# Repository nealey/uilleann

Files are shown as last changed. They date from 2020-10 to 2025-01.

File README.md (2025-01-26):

Uilleann
=======

This is my work to model a 3D printable Uilleann Pipe full set.

I need a better name for this project.

Printing Advice
=============

Reeds
------

The Daye drones feature 3D printable reeds,
based on the laudable work of Animatorgeek.
Reeds need to simulate natural cane,
so the following print settings should be used on every reed:

Fill pattern: Aligned Rectilinear  
Fill density: 100%  
Fill angle: 90°  
Bottom solid layers: 0  
Layer height: 0.05  
Perimiters: 1  
Seam position:  Aligned (or whatever gets seams off the reed and onto the base)  
Top solid layers: 0  

Some light sanding may be required after printing.

Daye
====

Based on David Daye's Budget Drones and Penny Chanter owned by me.
David Daye has published extensive notes on how to recreate his builds
at <https://daye1.com/>, including measurements for these parts.

Rowsome
=======

This is based on the O'Flynn Leo Rewsome set,
documented at pipers.id.

http://pipers.ie/source/section/?sectionId=8 has been invaluable, providing
detailed documentation of measurements of pipes.

* [photos](https://pipers.ie/source/gallery?galleryId=115)
* [diagrams](http://pipers.ie/source/gallery?galleryId=1353)

Decorations
----------

The diagrams didn't specify exact values for every measurement,
so I took some aesthetic liberties with some parts (mostly decorative ones).

Bump-Outs
----------

I think this chanter has some extra keys that I'm not going to implement,
so I skipped a lot of the bump-out warty things on the side.

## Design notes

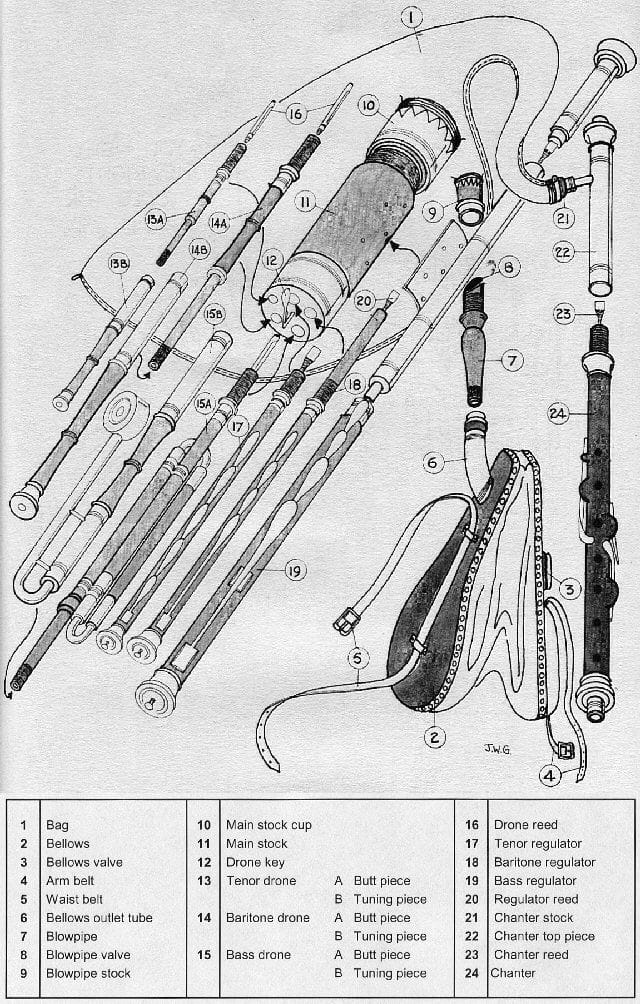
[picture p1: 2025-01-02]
doc/full-set-names.jpg

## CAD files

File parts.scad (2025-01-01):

// Make circles circular in final renders.
$fn = $preview ? 0 : 60;

module brass() {
  color("gold") children();
}

module derlin() {
  color("steelblue") children();
}

// tube creates a hollow cylinder
module tube(h=10, id=5, od=10) {
  difference() {
    cylinder(h=h, d=od);
    cylinder(h=h, d=id);
  }
}

// default height of rings
rings_height = 1.8;

// rings of adornment.
// This engraves two rings, 1.4mm apart, at a depth of 0.4.
module rings(h=0.4, d=1, depth=0.4, spacing=1.4) {
  tube(h=h, id=d-depth, od=d);
  translate([0, 0, spacing]) tube(h=h, id=d-depth, od=d);
}

// default brass tube thickness
brass_thickness = 0.75;

// brass_tube creates a chamfered hollow cylinder with given inside diameter,
// and wall thickness of 0.75.
// Decorative rings are etched into the top and bottom.
module brass_tube(h=10, d=10, t=brass_thickness) {
  id = d;
  od = id + (t*2);
  cd = (id + od) / 2; // Chamfer diameter

  brass() {
    difference() {
      tube(h=h, id=id, od=od);

      // Chamfered ends
      translate([0, 0, 0]) cylinder(h=1, d1=cd, d2=id);
      translate([0, 0, h-1]) cylinder(h=1, d1=id, d2=cd);

      translate([0, 0, 2]) rings(d=od);
      translate([0, 0, h-2-rings_height]) rings(d=od);
    }
  }
}

// derlin_tube is a non-chamfered sky blue tube.
// I use blue so it's easier to see in preview.
module derlin_tube(h=10, id=5, od=10) {
  derlin() {
    tube(h=h, id=id, od=od);
  }
}

// derlin_stop is a derlin tube, chamfered on one end.
module derlin_stop(h=10, id=5, od=10) {
  chamferh = h/5;
  derlin() {
    difference() {
      union() {
        cylinder(h=h-chamferh, d=od);
        translate([0, 0, h-chamferh]) cylinder(h=chamferh, d1=od, d2=id);
        }
      cylinder(h=h, d=id);
      }
    }
}

// default bell height
bell_height = 17;

// derlin_bell makes a decorative flared bell.
// od will default to 33% larger than id.
module derlin_bell(h=bell_height, id=5, od=0) {
  chamferh = 1;
  chamferd = 1;
  ringsmargin = 1;
  toph = rings_height + ringsmargin*2 + chamferh;
  flareh = h - toph;
  od = (od == 0) ? (id * 1.33) : od;
  derlin() {
    difference() {
      union() {
        cylinder(h=flareh, d1=id, d2=od);
        translate([0, 0, flareh]) cylinder(h=toph-chamferh, d=od);
        translate([0, 0, flareh+toph-chamferh]) cylinder(h=chamferh, d1=od, d2=od-chamferd);
      }
      cylinder(h=h, d=id);
      translate([0, 0, flareh + ringsmargin]) rings(d=od);
    }
  }
}

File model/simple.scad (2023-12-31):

// Based on O'Flynn Rowsome Chanter Measurements
// http://pipers.ie/source/media/?mediaId=31307&galleryId=1353

// DIameter of screw hole
Screwhole = 4; // [1:10]

// Part to generate
Part = "all"; // [all, top-front, top-back, bottom-front, bottom-back]


module metal() {
    color("silver") children();
}

module leather() {
    color("sienna") children();
}

module ivory() {
    color("wheat") children();
}

module wood() {
    color("saddlebrown") children();
}

// A shape like a hamburger patty
module patty(h, d) {
    intersection() {
        cylinder(h=h, d=d);
        translate([0, 0, h/2]) {
            resize([d, d, h*3]) {
                sphere(d=d);
            }
        }
    }
}    

// A cylinder with something like a compression fitting around it
module ringyding(h, id, od) {
    margin = h * 0.1;
    union() {
        leather() cylinder(h=h, d=id);
        translate([0, 0, margin]) ivory() patty(h=h*0.8, d=od);
    }
}

// A fillet is a sort of trumpet bell shape
module fillet(h, d1, d2) {
    r = abs(d1-d2)/2;
    resize([d1, d1, h]) {
        rotate_extrude() {
            translate([d2/2, 0, 0]) {
                difference() {
                    square([r, r]);
                    translate([r, r]) circle(r=r);
                }
            }
        }
    }
}

// An upside-down fillet
module tellif(h, d2, d1) {
    translate([0, 0, h]) mirror([0, 0, 1]) fillet(h, d1, d2);
}

// Absolutely nothing: helps make the code look better
module nothing(h) {
}

// Just a rotated cylinder
// h: height of the *top* of the protrusion
// d: height of the protrusion (diameter?)
// protrusion: amount of protrusion
module bumpout(h, d, protrusion) {
    intersection() {
        translate([0, -protrusion, h-d]) {
            cylinder(h=d, d=20.4);
        }
        translate([0, -protrusion, h-d/2]) {
            sphere(d=protrusion*4);
        }
        translate([0, 0, h-d]) {
            cylinder(h=d, d1=19, d2=50);
        }
    }
}


// A tonehole with :
// * height=h
module tonehole(h) {
    translate([0, 5, h]) {
        rotate(a=90, v=[1, 0, 0]) {
            resize([Screwhole, Screwhole, 100]) {
                cylinder(h=100, d=100);
            }
        }
    }
}

module chanter() {
    difference() {
        union() {
            translate([0, 0,  0]) metal() cylinder(h=22.0, d=17.1);
            translate([0, 0, 22]) wood() cylinder(h=23.5, d=17.1);  // Rings go around this
            
            // Decorative stuff on the bottom
            translate([0, 0, 32]) {          
                translate([0, 0, 0.0]) ivory() patty(h=3.4, d=28.7);
                translate([0, 0, 3.4]) leather() fillet(h=1.8, d1=27, d2=22);
                translate([0, 0, 4.1]) ringyding(h=4.1, id=21, od=24);
                translate([0, 0, 8.2]) ringyding(h=5.3, id=21, od=24);
            }

            // A taper on that bottom ring so it will print nicely
            translate([0, 0, 12]) wood() tellif(h=20, d1=25.5, d2=100);
            
            // Main body
            translate([0, 0, 45.5]) wood() cylinder(h=244.9, d1=20.4, d2=18);
            
            // Top decoration
            translate([0, 0, 290.4]) {
                color("silver") cylinder(h=40.8, d=17);
                
                translate([0, 0,  0.0]) ringyding(h=5.5, id=19, od=21);
                translate([0, 0,  5.5]) nothing(h=9.7); // metal
                translate([0, 0, 15.2]) ringyding(h=4.3, id=18, od=20.7);
                translate([0, 0, 19.5]) nothing(h=6.7); // metal
                translate([0, 0, 26.2]) ivory() patty(h=2, d=20.2);
                translate([0, 0, 28.2]) leather() tellif(h=8, d2=19, d1=23);
                translate([0, 0, 36.2]) ivory() patty(h=4.6, d=25.4);
            }
            
            // I presume this protects the reed and provides a place for tubing to connect
            translate([0, 0, 324.5]) metal() cylinder(h=32.7, d=14.8);
            
            // Bumpouts
            // These angles are my best guess based on photos
            rotate(220) wood() bumpout(161.2, 14.8, 6); // protrusion guessed
        }

        // Tone Holes!
        translate([0, 0, 5]) { // This offset is specified nowhere. I'm guessing to make it fit the bumpouts.
            rotate(180) tonehole(263.0); // back D
            rotate(0) tonehole(246.4); // C♯
            rotate(0) tonehole(216.2); // B
            rotate(0) tonehole(182.0); // A
            rotate(0) tonehole(147.4); //  G
            rotate(0) tonehole(116.2); // F♯
            rotate(0) tonehole(84.7); // E
            rotate(-10) tonehole(53.3); // E♭
        }
    }
}

intersection() {
    chanter();
    cube(400);
}

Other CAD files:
daye/common.scad
rowsome/chanter-full.scad
daye/chanter/chanter-bottom.scad
daye/chanter/chanter-top.scad
daye/chanter/chanter.scad
daye/chanter/reed.scad
daye/drones/assembly.scad
daye/drones/baritone/assembly.scad
daye/drones/baritone/reed-body.scad
daye/drones/baritone/reed.scad
daye/drones/baritone/tuner-barrel.scad
daye/drones/baritone/tuner-end.scad
daye/drones/bass/assembly.scad
daye/drones/tenor/assembly.scad
daye/drones/tenor/tuner-barrel.scad
daye/drones/tenor/tuner-end.scad
rowsome/chanter.scad

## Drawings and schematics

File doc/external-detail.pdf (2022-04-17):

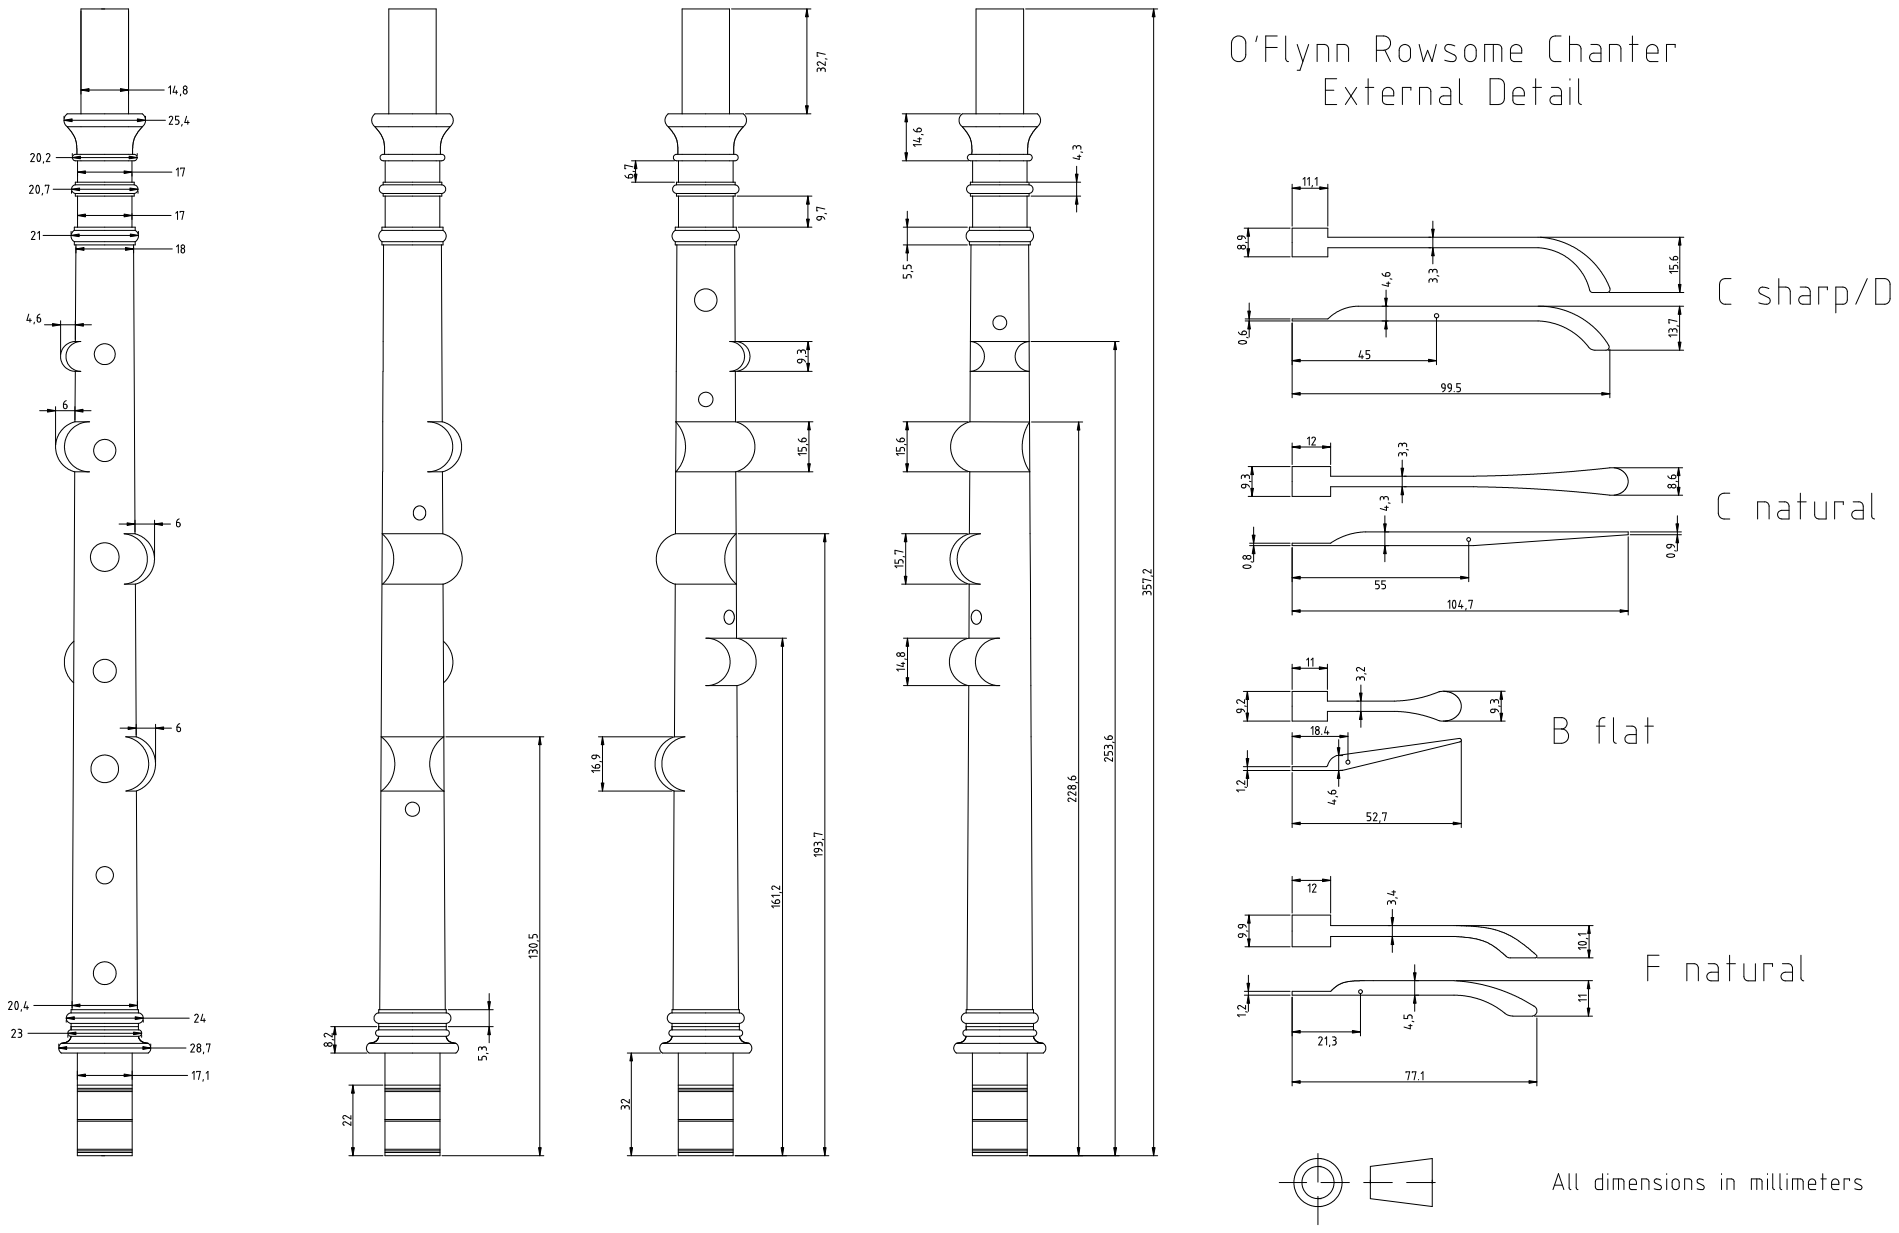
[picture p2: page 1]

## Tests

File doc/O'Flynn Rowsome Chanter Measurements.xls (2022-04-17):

All measurements in millimetres
OAL: 357.2 [±0.05] |  |  |  |  |  | Bore comments
Minimum bore diameter: 5.57 [±0.005] |  |  |  |  |  | Bore contained two rushes, each having a diameter of 0.9 and a length of 272
Round |  |  | Oval |  |  |  |  | Tone holes
Probe # | Actual diameter [±0.005] | Insertion distance [±0.5] | Probe # | Actual diameter [±0.005] | Insertion distance [±0.5] |  |  | Tonehole | Transverse diameter [±0.005] | Longitudinal diameter [±0.005] | Chimney height [±0.05] | Distance from bell to lower tonehole edge [±0.05] | Comments
71 | 7.1 | 357 | - | - | - | Approximate reed dimensions |  | back D | 6.04 | 7.95 | 10.1 | 263
70 | 7 | 344 | - | - | - | Overall length | 86.5 | high C sharp/D | 4.39 | 4.36 | 11.1 | 257.3
69 | 6.91 | 344 | - | - | - | Head width | 12.8 | C sharp | 6.42 | 6.57 | 11.3 | 246.4
68 | 6.8 | 344 | - | - | - | Scrape length | 22.5 | C natural | 4.5 | 4.5 | 11.5 | 233.3
67 | 6.7 | 344 | - | - | - | Staple length | 55.5 | B | 6.89 | 6.96 | 11.3 | 216.2
66 | 6.6 | 344 | - | - | - | Staple inner diameter | 4.5 | B flat | 4.34 | 4.47 | 12.6 | 198
65 | 6.51 | 344 | - | - | - | Staple external diameter | 5.7 | A | 8.85 | 9.06 | 11.4 | 182
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

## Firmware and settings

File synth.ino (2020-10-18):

#include <Audio.h>
#include <Wire.h>
#include <Adafruit_NeoTrellisM4.h>
#include <SFE_MicroOLED.h>
#include <SparkFun_Qwiic_Button.h>
#include <Adafruit_MPR121.h>
#include "synth.h"
#include "patches.h"
#include "notes.h"
#include "fingering.h"

#define KNEE_OFFSET 0
#define KEY_OFFSET 2

float cmaj_low[8] = { 130.81, 146.83, 164.81, 174.61, 196.00, 220.00, 246.94, 261.63 };
float cmaj_high[8] = { 261.6, 293.7, 329.6, 349.2, 392.0, 440.0, 493.9, 523.3 };

AudioEffectEnvelope *envs[] = {&env1, &env2, &env3, &env4};
AudioSynthWaveformSineModulated *oscs[] = {&osc1, &osc2, &osc3, &osc4};

int currentPatch = 0;

Adafruit_MPR121 cap = Adafruit_MPR121();
Adafruit_NeoTrellisM4 trellis = Adafruit_NeoTrellisM4();
MicroOLED oled(9, 1);
QwiicButton bag;

// Hat tip to Kyle Gann
// https://www.kylegann.com/tuning.html
float JustPitches[MaxNote + 1];
void setupJustPitches(uint8_t baseNote, float basePitch) {
  JustPitches[baseNote +  0] = basePitch *  1 /  1;
  JustPitches[baseNote +  1] = basePitch * 16 / 15;
  JustPitches[baseNote +  2] = basePitch *  9 /  8;
  JustPitches[baseNote +  3] = basePitch *  6 /  5;
  JustPitches[baseNote +  4] = basePitch *  5 /  4;
  JustPitches[baseNote +  5] = basePitch *  4 /  3;
  JustPitches[baseNote +  6] = basePitch * 45 / 32;
  JustPitches[baseNote +  7] = basePitch *  3 /  2;
  JustPitches[baseNote +  8] = basePitch *  8 /  5;
  JustPitches[baseNote +  9] = basePitch *  5 /  3;
  JustPitches[baseNote + 10] = basePitch *  9 /  5;
  JustPitches[baseNote + 11] = basePitch * 15 /  8;

  // Octaves
  for (int note = baseNote; note < baseNote + 12; note++) {
    for (int i = 1; i < 9; i++) {
      int multiplier = 1<<i;
      int shift = i*12;
      int upNote = note + shift;
      int dnNote = note - shift;
      
      if (upNote <= MaxNote) {
        JustPitches[upNote] = JustPitches[note] * multiplier;
      }
      if (dnNote >= 0) {
        JustPitches[dnNote] = JustPitches[note] / multiplier;
      }
    }
  }
}

void loadPatch(Patch p) {
  for (int i=0; i<4; i++) {
    Operator op = p.operators[i];

    oscs[i]->amplitude(op.gain);
    envs[i]->delay(op.delay);
    envs[i]->attack(op.attack);
    envs[i]->hold(op.hold);
    envs[i]->decay(op.decay);
    envs[i]->sustain(op.sustain);
    envs[i]->release(op.release);
  }
  feedback.gain(0, p.feedback);
}

void setup(){
  setupJustPitches(NOTE_D4, PITCH_D4);
  pinMode(LED_BUILTIN, OUTPUT);

  // Wire.begin needs a moment
  delay(100);
  Wire.begin();

  // Initialize OLED display
  oled.begin();
  oled.clear(ALL);

  // Initialize bag
  bag.begin();

  // Initialize the Trellis
  trellis.begin();

  // Initialize touch sensor
  bool blink = true;
  while (!cap.begin(0x5A)) {
    oled.clear(PAGE);
    oled.setCursor(0, 0);
    oled.print("No Pipe?");
    oled.display();

    trellis.setPixelColor(0, blink?0xff6666:0);
    blink = !blink;
    delay(200);
  }

  // Set aside some memory for the audio library  
  AudioMemory(120);

  // initialize tunables
  updateTunables(3, 0);

  // Initialize processor and memory measurements
  AudioProcessorUsageMaxReset();
  AudioMemoryUsageMaxReset();
}

void setPitch(float freq) {
  for (int i=0; i<4; i++) {
    Operator op = Bank[currentPatch].operators[i];
    oscs[i]->frequency(op.baseFrequency + freq*op.multiplier);
  }
}

void noteOn(float freq) {
  AudioNoInterrupts();
  for (int i=0; i<4; i++) {
    Operator op = Bank[currentPatch].operators[i];
    oscs[i]->frequency(op.baseFrequency + freq*op.multiplier);
    envs[i]->noteOn();
  }
  AudioInterrupts();
}

void noteOff() {
  AudioNoInterrupts();
  for (int i=0; i<4; i++) {
    envs[i]->noteOff();
  }
  AudioInterrupts();
}

#define BUTTON_UP 0
#define BUTTON_DOWN 8
#define BUTTON_PITCH 24
#define BUTTON_VOLUME 25

#define INIT_PITCH_ADJUST 0
#define INIT_GAIN 0.1
#define INIT_PATCH 0

int16_t pitchAdjust;
float gain;
int patch;

void updateTunables(uint8_t buttons, int note) {
  // Pitch adjust if playing A
  if (!note || (note == NOTE_A4)) {
    switch (buttons) {
    case 3:
      pitchAdjust = INIT_PITCH_ADJUST;
      break;
    case 2:
      pitchAdjust += 4;
      break;
    case 1:
      pitchAdjust -= 4;
      break;
    }
  }

  float adj = pow(2, pitchAdjust / 32768.0);
  setupJustPitches(NOTE_D4, PITCH_D4*adj);
  trellis.setPixelColor(BUTTON_PITCH, trellis.ColorHSV(uint16_t(pitchAdjust), 255, 80));

  if (!note || (note == NOTE_G4)) {
    // Volume adjust if playing G
    switch (buttons) {
    case 3:
      gain = INIT_GAIN;
      break;
    case 2:
      gain = min(gain+0.005, 1.0);
      break;
    case 1:
      gain = max(gain-0.005, 0.0);
      break;
    }
  }

  mixL.gain(0, gain);
  mixR.gain(0, gain);
  trellis.setPixelColor(BUTTON_VOLUME, trellis.ColorHSV(uint16_t(gain * 65535), 255, 80));

  if (!note || (note == NOTE_CS5)) {
    if (buttons == 3) {
      patch = INIT_PATCH;
    } else if (trellis.justPressed(BUTTON_DOWN)) {
      patch -= 1;
    } else if (trellis.justPressed(BUTTON_UP)) {
      patch += 1;
    }

    // wrap
    int bankSize = sizeof(Bank) / sizeof(Bank[0]);
    patch = (patch + bankSize) % bankSize;

    Patch p = Bank[patch];
    loadPatch(p);

    oled.clear(PAGE);
    oled.setFontType(0);
    oled.setCursor(0, 0);
    oled.print(p.name);
    oled.setCursor(0, 10);
    oled.print("Patch ");
    oled.print(patch);
    oled.display();
  }
}

const uint8_t CLOSEDVAL = 0x30;
const uint8_t OPENVAL = 0x70;
const uint8_t GLISSANDO_STEPS = OPENVAL - CLOSEDVAL;

bool playing = false;

void loop() {
  uint8_t keys = 0;
  uint8_t note;
  uint8_t glissandoKeys = 0;
  uint8_t glissandoNote;
  float glissandoOpenness = 0;
  bool silent = false;
  bool knee = cap.filteredData(KNEE_OFFSET) < CLOSEDVAL;
  uint8_t buttons = trellis.isPressed(BUTTON_DOWN)?1:0 | trellis.isPressed(BUTTON_UP)?2:0;

  trellis.tick();

  for (int i = 0; i < 8; i++) {
    uint16_t val = max(cap.filteredData(i+KEY_OFFSET), CLOSEDVAL);
    float openness = ((val - CLOSEDVAL) / float(GLISSANDO_STEPS));

    // keys = all keys which are at least touched
    // glissandoKeys = all keys which are fully closed
    // The glissando operation computes the difference.
    if (openness < 1.0) {
      glissandoOpenness = max(glissandoOpenness, openness);
      bitSet(keys, i);

      if (openness == 0.0) {
        bitSet(glissandoKeys, i);
      }
    }
    
    // print key states
    //trellis.setPixelColor(7 - i, trellis.ColorHSV(65536/12, 255, 120*openness));
    trellis.setPixelColor(7 - i, trellis.ColorHSV(22222*openness, 255, 40));
  }
  
  note = uilleann_matrix[keys];
  glissandoNote = uilleann_matrix[glissandoKeys];

  bool alt = note & 0x80;
  bool galt = glissandoNote & 0x80;
  note = note & 0x7f;
  glissandoNote = glissandoNote & 0x7f;

  // All keys closed + knee = no sound
  if (knee) {
    if (keys == 0xff) {
      silent = true;
    }
  }

  // Jump octave if the bag is squished
  //bag = !digitalRead(BAG);
  if (bag.isPressed()) {
    if (keys & bit(7)) {
      note += 12;
      glissandoNote += 12;
    }
  }

  // Read some trellis button states
  if (buttons) {
    updateTunables(buttons, note);
  }

  if (silent) {
    noteOff();
    playing = false;
  } else {
    // Calculate pitch, and glissando pitch
    uint16_t pitch = JustPitches[note];
    uint16_t glissandoPitch = JustPitches[glissandoNote];

    if (alt) {
      biquad1.setLowShelf(0, 2000, 0.2, 1);
    } else {
      biquad1.setHighShelf(0, 1000, 1.0, 1);
    }
  
    // Bend pitch if fewer than 3 half steps away
    if (abs(glissandoNote - note) < 3) {
      float diff = glissandoPitch - pitch;
      pitch += diff * glissandoOpenness;
    }

    if (playing) {
      setPitch(pitch);
    } else {
      noteOn(pitch);
    }
    playing = true;
  }
}

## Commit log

2020-10-17 Pitch adjustment
2020-11-11 Working on teensy 4.0 + PAJ7620
2020-11-25 Now you can adjust pitch and intonation
2022-04-17 v3 of button design
    It sticks more than I like, bringing back v2 elements next
    [O'Flynn Rowsome Chanter Measurements.xls, button-all.scad, button-container.scad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]
2022-04-18 One last change to button before abandoning it
    [button.scad]
2022-05-01 First stab at a PCB
    [pcb-B_Cu.gbr, pcb-B_Mask.gbr, pcb-B_Paste.gbr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]
2022-05-01 Second stab at a PCB
    [pcb.kicad_pcb, pcb.kicad_sch]
2023-04-20 Giving up on PCB
    [pcb-B_Cu.gbr, pcb-B_Mask.gbr, pcb-B_Paste.gbr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]
2023-04-20 Designing buttons turns out to be difficult.
    [button-all.scad, button-container.scad, button-container.stl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]
2023-12-31 Remove button, bad idea
2023-12-31 check in some work on a simplified chanter
    [simple.scad]
2025-01-01 Transition to a solely physical bagpipe design
    [chanter-full.scad, chanter.scad, chanter.stl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]
2025-01-01 Done with tenor tuner parts
    [drone-tenor-tuner.scad, parts.scad]
2025-01-02 more daye drone work, organization
    [assembly.scad, chanter-full.scad, chanter.scad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]
2025-01-03 Add bass drone tuner
    [assembly.scad, common.scad]
2025-01-19 try 1 at reed body
    [reed-body.scad]
2025-01-26 Add a printable single reed!
    [reed-body.scad, reed.scad]
2025-01-27 reed refinements
    [reed.scad]
2025-02-01 start work on chanter reed
    [reed.scad]
2025-02-19 Add penny chanter
    [chanter.scad]
2025-02-19 completed penny chanter
    [chanter-bottom.scad, chanter-top.scad, chanter.scad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]
2025-02-20 Further tuning of chanter
    [chanter-bottom.scad, chanter-top.scad, chanter.scad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]
